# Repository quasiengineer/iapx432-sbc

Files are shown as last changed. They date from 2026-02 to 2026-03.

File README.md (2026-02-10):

# System board for Intel APX 432 GDP
FPGA-based single board computer to run iAPX 432 GDP

## Board

Full schematics in [pdf format](./images/schematic.pdf)

Here is shown only FPGA part of the board:
schematic

Archive with gerber files and drill locations could be found [here](./pcb/manufacturing.zip)

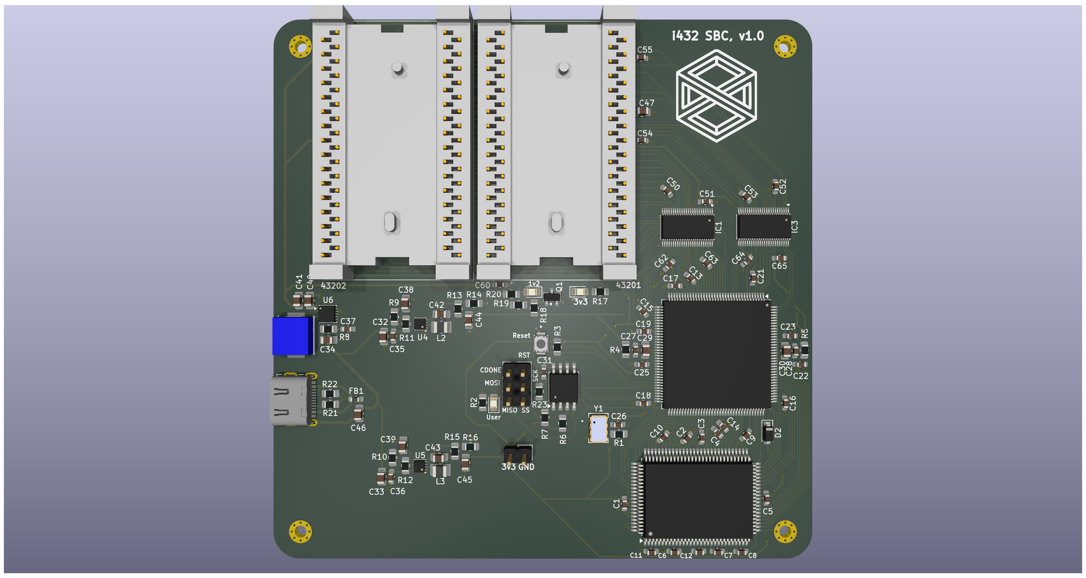
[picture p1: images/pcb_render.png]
pcb


Bill of material in [CSV format](./pcb/bom.csv)

| Reference | Qty | Value | Mouser Part Number |
|---|---|---|---|
| Y1 | 1 | 250Mhz | 972-XLH536250000000I |
| U1 | 1 | SRAM | 870-61LPS12836A5TQL  |
| U2 | 1 | ICE40 | 842-ICE40HX4K-TQ144  |
| FB1 | 1 | Ferrite_Bead | 81-BLM18BD152SH1D |
| D1 | 1 | Red | 710-150080RS75000 |
| D3,D4 | 2 | Green | 710-150080GS75000 |
| J1 | 1 | Type-C | 656-DX07S016JA1R1500 |
| L1 | 1 | 1u5, 5A | 652-SRP6530A-1R5M |
| L2,L3 | 2 | 0u68, 5.5A | 652-SRP2512-R68M |
| J3 | 1 | Power | 649-67997-200HLF |
| J2 | 1 | FPGA programming / UART | 649-1012938190604BLF |
| SW1 | 1 | FPGA Reset | 640-SWT0010015016SSA |
| Q1 | 1 | MMBT3904 | 637-MMBT3904 |
| D2 | 1 | 1N5819 | 621-1N5819HW-F |
| R11,R12,R13,R14,R19 | 5 | 100k | 603-RT0805DRE07100KL |
| R23 | 1 | 470R | 603-RT0805BRD07470RL |
| R21,R22 | 2 | 5k1 | 603-RC0805FR-075K1L  |
| R2,R18 | 2 | 4k7 | 603-RC0805FR-074K7L  |
| R16 | 1 | 34k8 | 603-RC0805FR-0734K8L |
| R17,R20 | 2 | 2k2 | 603-RC0805FR-072K2L  |
| R15 | 1 | 158k | 603-RC0805FR-07158KL |
| R1 | 1 | 22R | 603-RC0805FR-1322RL  |
| C43 | 1 | 33p | 603-CC805KRNPO9BN330 |
| C42 | 1 | 22p | 603-CC805JRNPO9BN220 |
| R9,R10 | 2 | 10 | 603-AF0805FR-0710RL  |
| R4,R5,R8 | 3 | 100R | 603-AC0805FR-13100RL |
| R3,R6,R7 | 3 | 10k | 603-AA0805FR-0710KL  |
| U6 | 1 | TPS63002 | 595-TPS63002DRCR |
| IC3 | 1 | Control signals | 595-LVC16T245DGVRG4  |
| IC1 | 1 | Address/data bus | 595-LVC16T245DGVRG4  |
| U4,U5 | 2 | LX7167ACLD-TR | 494-LX7167ACLD-TR |
| U3 | 1 | Bitstream flash | 454-W25Q16JVSSIQ |
| C38,C39,C46,C47 | 4 | 1u | 187-CL21B105KPFNNNE  |
| C29,C30,C32,C33,C44,C45 | 6 | 22u | 187-CL21A226MAYNNNE  |
| C34,C40,C41 | 3 | 10u | 187-CL21A106KQFNNNG  |
| C1..C19,C21,C22,C23,C25..C28,C31,C35,C36,C37,C50..C65 | 46  | 100n | 187-CL10B104KB8NNNC  |
| U8 | 1 | 43202 | |
| U7 | 1 | 43201 | |

## FPGA bitstream

Here is compiled [bitsream](./gateware/build/iapx432-sbc.bin).
You can flash it to memory chip via SPI programmer (there is 6-pin header for that).

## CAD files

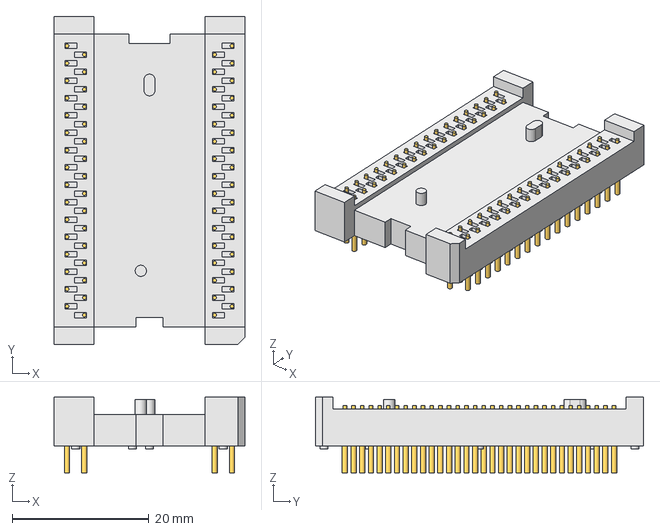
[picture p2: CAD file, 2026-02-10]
pcb/components/3d/3M_QUIP64.step
27.9 x 48.0 x 11.1 mm

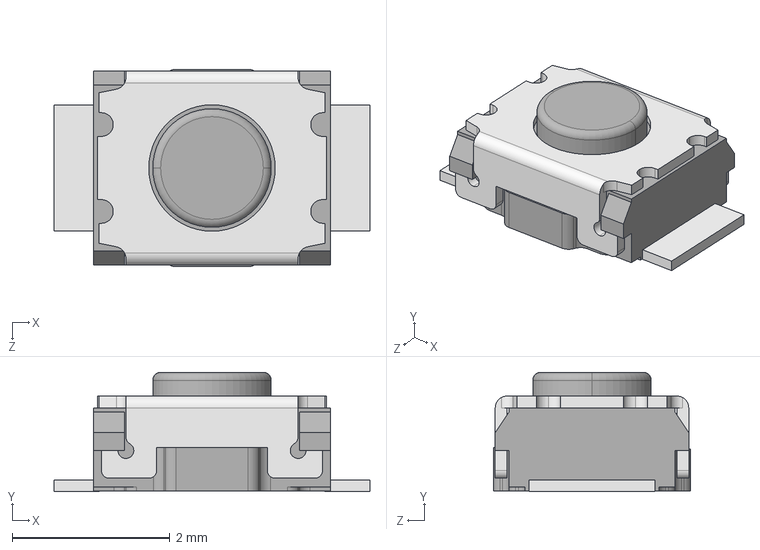
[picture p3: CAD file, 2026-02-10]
pcb/components/3d/SWT0010-015016SSA_revA.STEP
4.00 x 1.51 x 2.50 mm

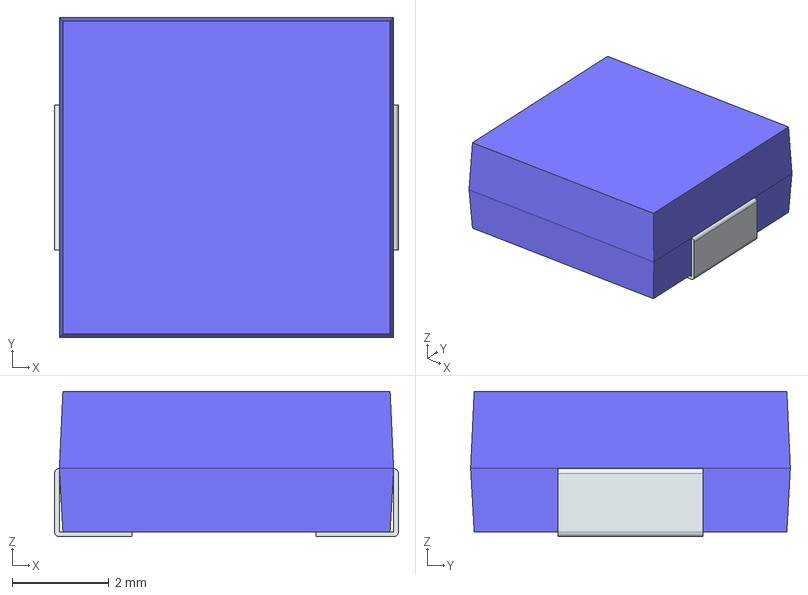
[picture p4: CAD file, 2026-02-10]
pcb/components/3d/SRP6530A-1R5M.stp
7.10 x 6.60 x 3.00 mm
FilletPin1
FilletPin2

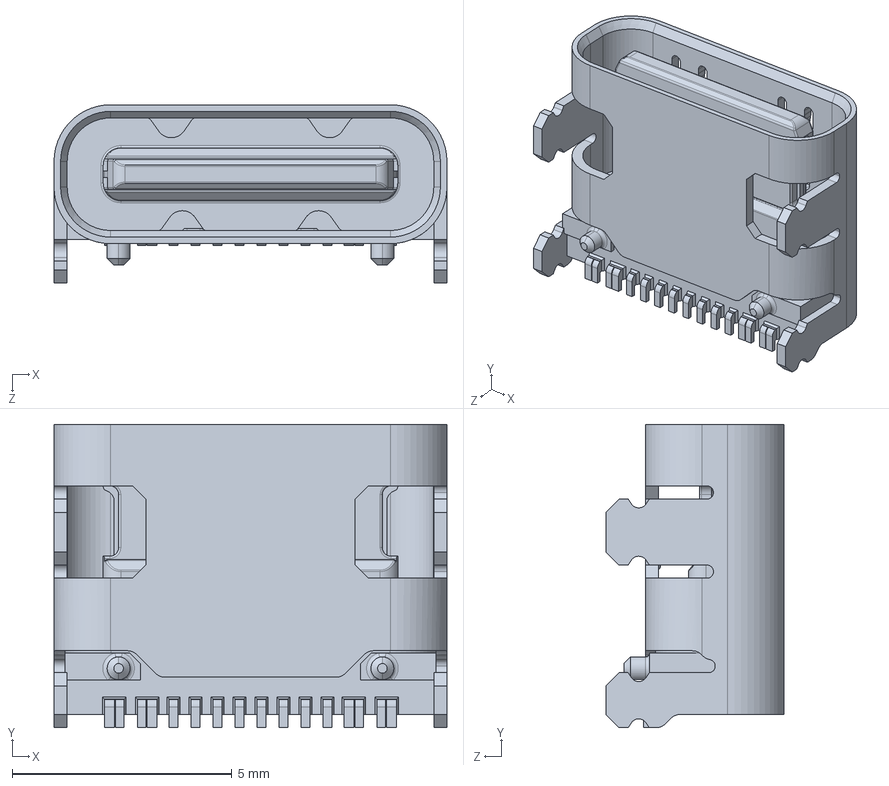
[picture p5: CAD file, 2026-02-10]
pcb/components/3d/DX07S016JA1R1500.stp
8.94 x 6.90 x 4.06 mm

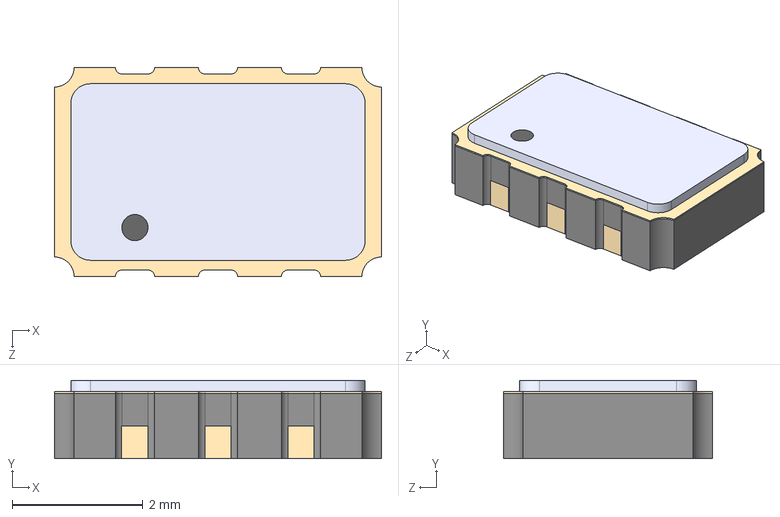
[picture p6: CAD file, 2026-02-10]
pcb/components/3d/XLH536250.000000I.STEP
5.00 x 1.20 x 3.20 mm

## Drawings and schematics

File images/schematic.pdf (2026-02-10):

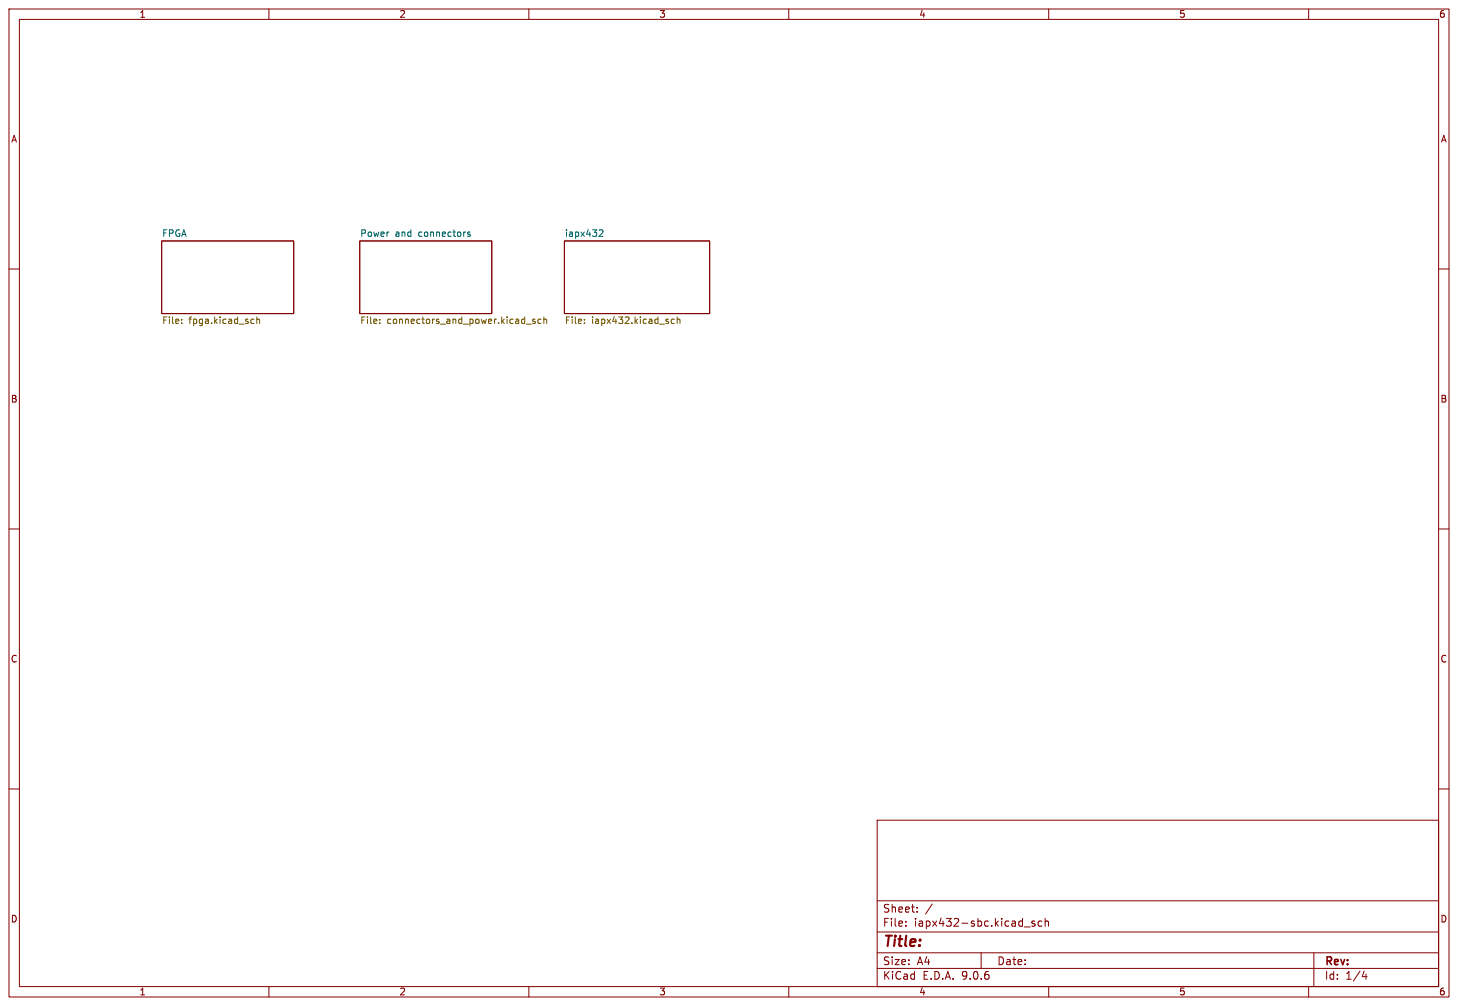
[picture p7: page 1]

iapx432 File: iapx432.kicad_sch Power and connectors File: connectors_and_power.kicad_sch

Id: 1/4 Title: File: iapx432-sbc.kicad_sch Sheet: /

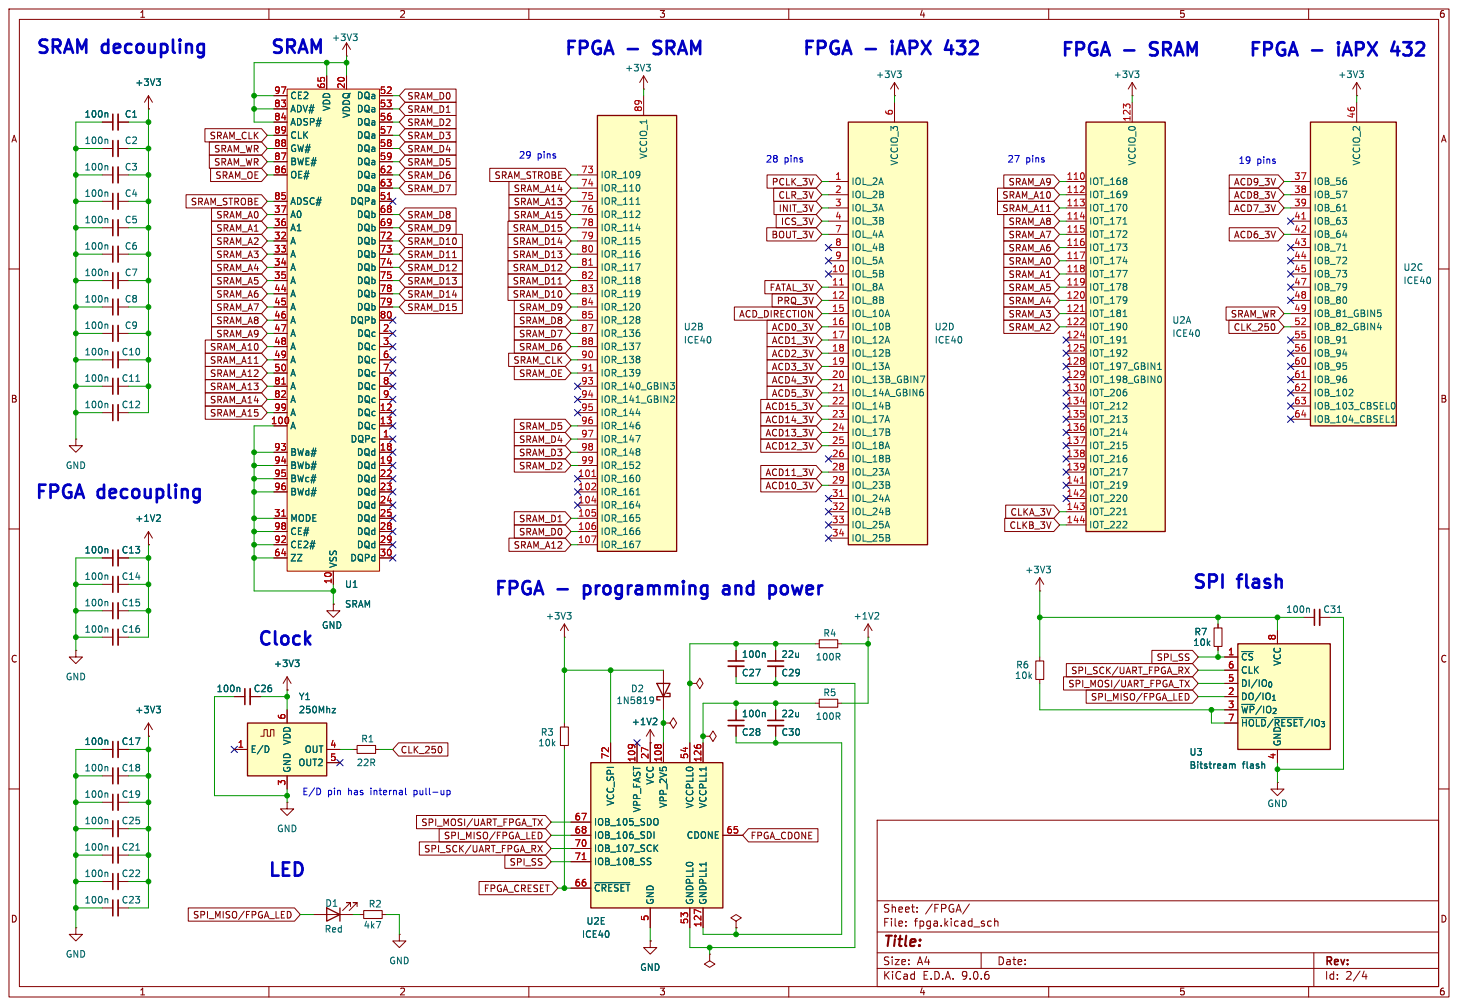
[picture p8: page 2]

+3V3 GND
CE2 97 ADV# 83 ADSP# 84 CLK 89 GW# 88 BWE# 87 OE# 86 ADSC# 85 A0 37 A1 36 A

Id: 2/4 Title: File: fpga.kicad_sch Sheet: /FPGA/

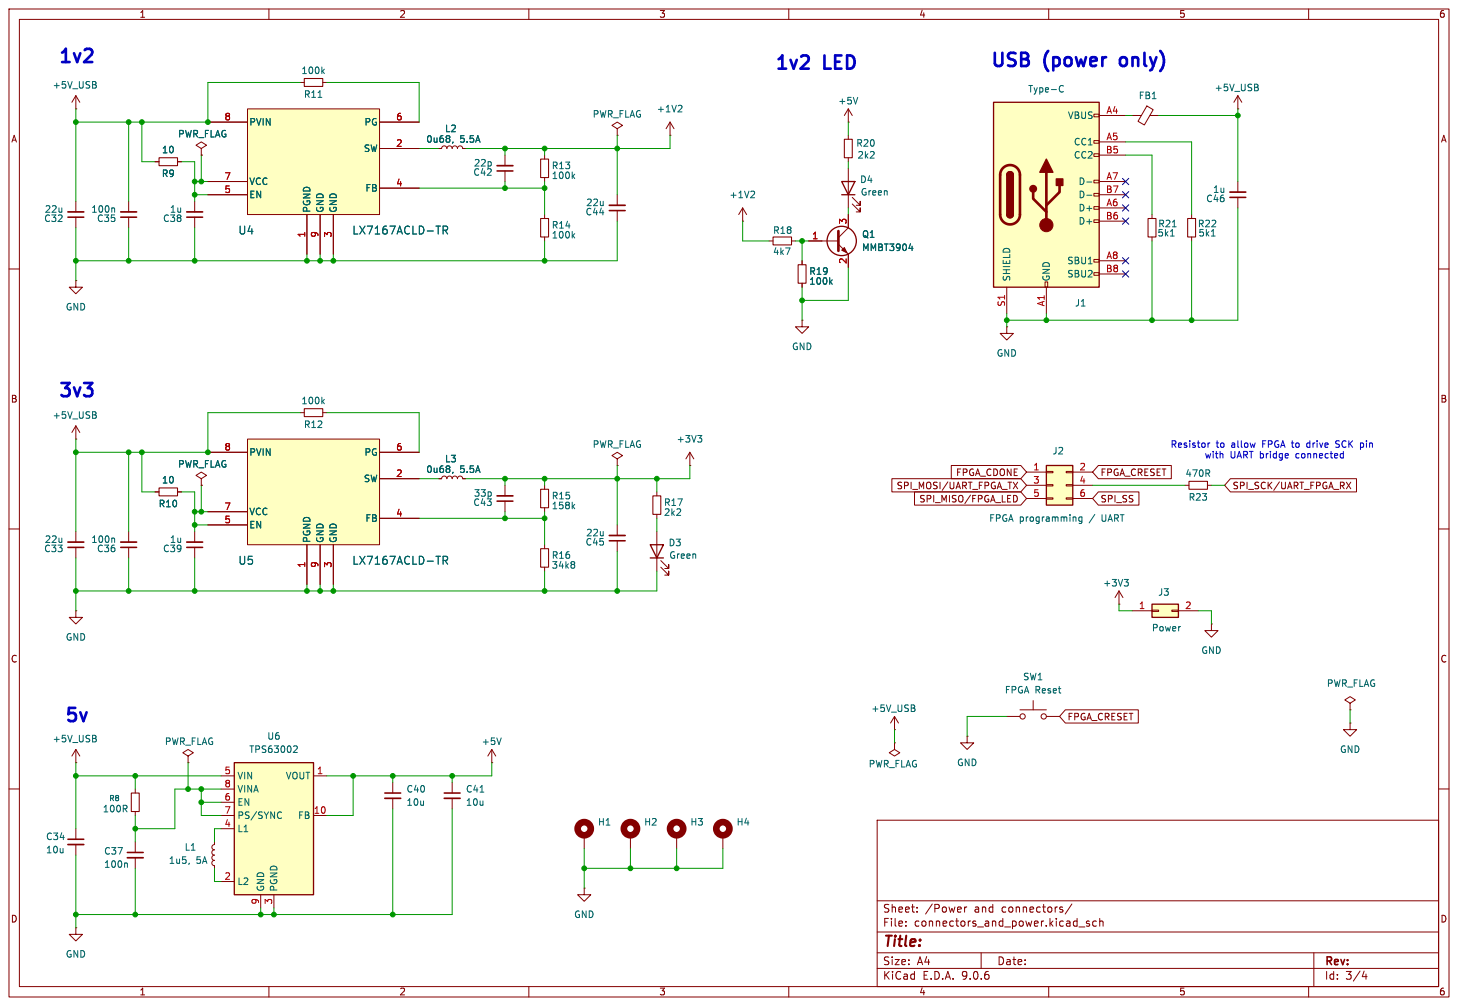
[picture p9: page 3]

3 PG 6 SW 2 FB 4 U4 LX7167ACLD-TR

3 PG 6 SW 2 FB 4 U5 LX7167ACLD-TR

VIN 5 VINA 8 EN 6 PS/SYNC 7

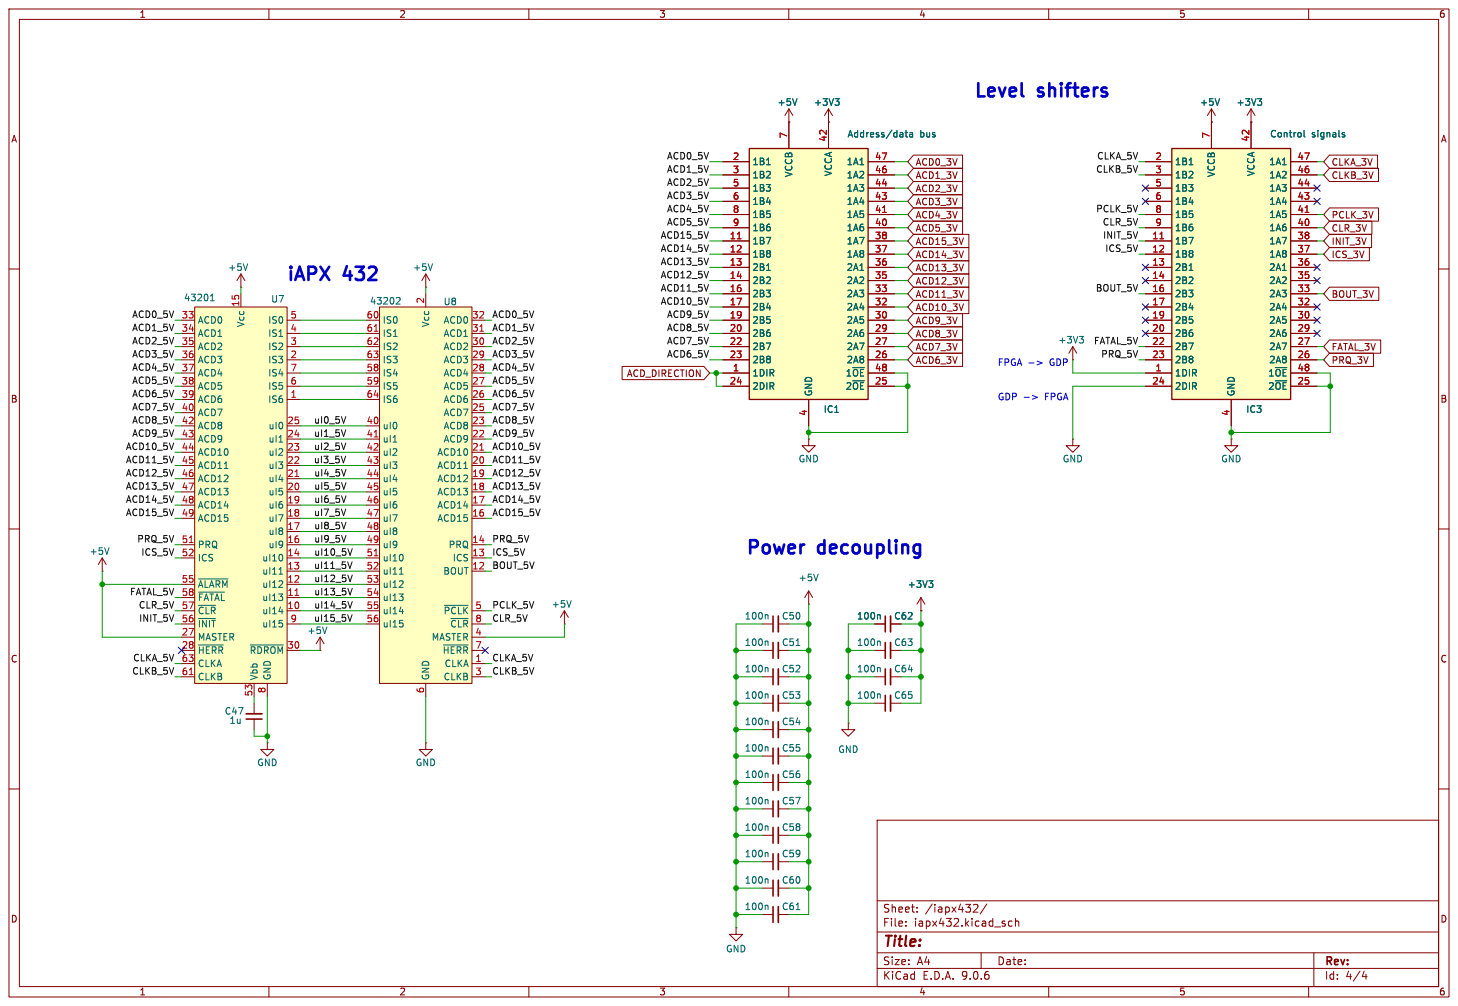
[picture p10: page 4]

ICS 13 BOUT 12 ~{PCLK}5 ~{CLR}8 MASTER 4 ~{HERR}7 CLKA 1 CLKB 3 Vcc 2 GND
ACD0 32 ACD1 31 ACD2 30 ACD3 29 ACD4 28 ACD5 27 ACD6 26 ACD7 25 ACD8 23 ACD9 22 ACD10 21 ACD11 20 ACD12 19 ACD13 18 ACD14 17 ACD15 16 PRQ 14

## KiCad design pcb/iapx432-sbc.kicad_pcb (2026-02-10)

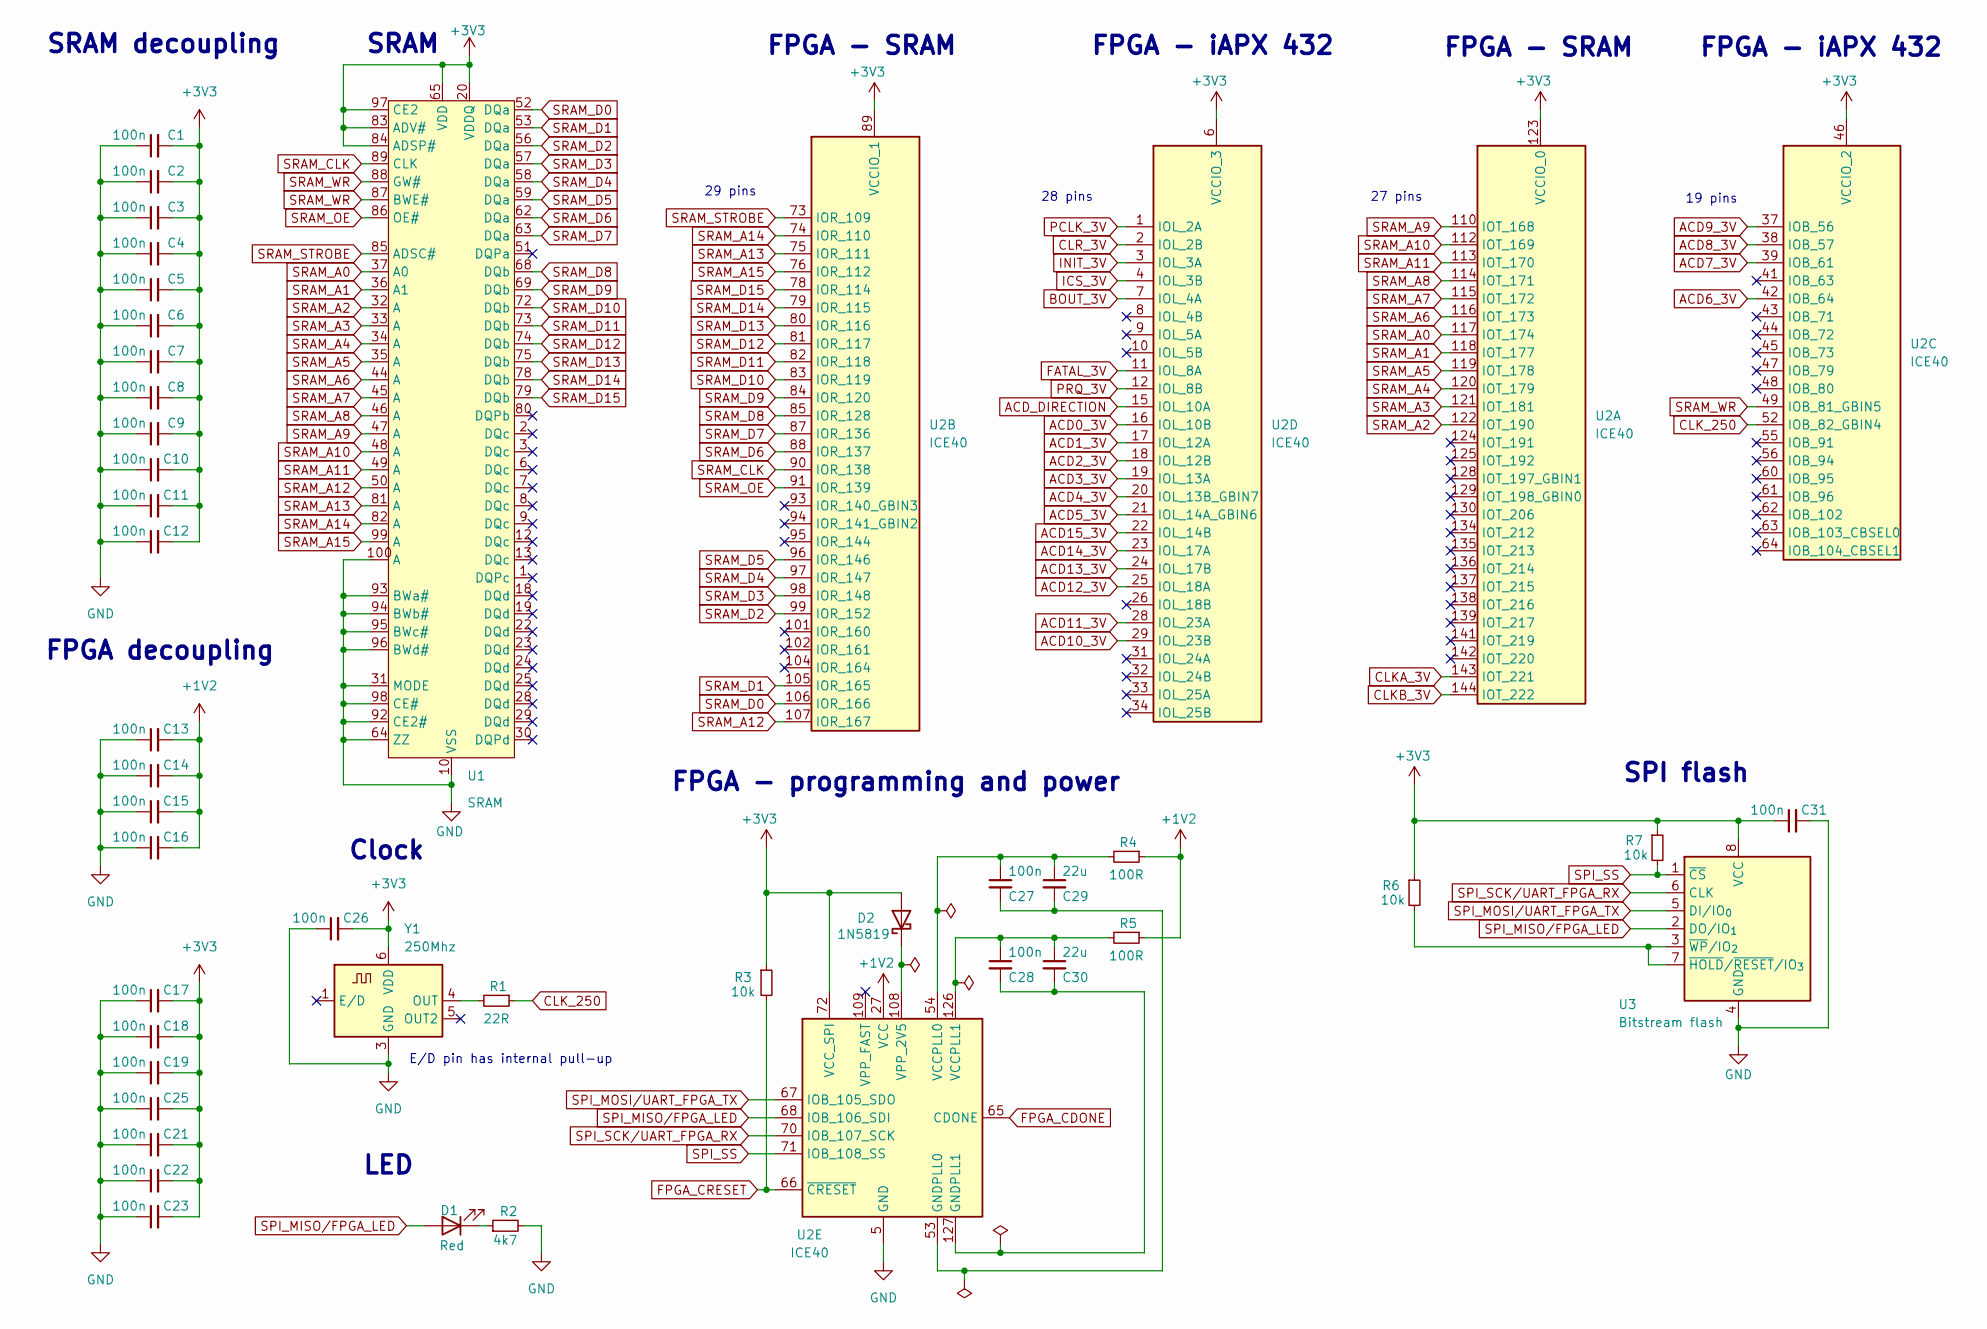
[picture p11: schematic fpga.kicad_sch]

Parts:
C1, C2, C3, C4, C5, C6, C7, C8, C9, C10, C11, C12, C13, C14, C15, C16, C17, C18, C19, C21, C22, C23, C25, C26, C27, C28, C31: 100n; C_0603_1608Metric_Pad1.08x0.95mm_HandSolder; Mouser Part Number 187-CL10B104KB8NNNC
C29, C30: 22u; C_0805_2012Metric_Pad1.18x1.45mm_HandSolder; Mouser Part Number 187-CL21A226MAYNNNE
D1: Red; LED_0805_2012Metric_Pad1.15x1.40mm_HandSolder; Mouser Part Number 710-150080RS75000
D2: 1N5819; D_SOD-123; Mouser Part Number 621-1N5819HW-F
R1: 22R; R_0805_2012Metric_Pad1.20x1.40mm_HandSolder; Mouser Part Number 603-RC0805FR-1322RL
R2: 4k7; R_0805_2012Metric_Pad1.20x1.40mm_HandSolder; Mouser Part Number 603-RC0805FR-074K7L
R3, R6, R7: 10k; R_0805_2012Metric_Pad1.20x1.40mm_HandSolder; Mouser Part Number 603-AA0805FR-0710KL
R4, R5: 100R; R_0805_2012Metric_Pad1.20x1.40mm_HandSolder; Mouser Part Number 603-AC0805FR-13100RL
U1: SRAM; PQFP-100_14x20mm_P0.65mm; Mouser Part Number 870-61LPS12836A5TQL
U2: ICE40; TQFP-144_20x20mm_P0.5mm; Mouser Part Number 842-ICE40HX4K-TQ144
U3: Bitstream flash; SOIC-8_5.3x5.3mm_P1.27mm; Mouser Part Number 454-W25Q16JVSSIQ
Y1: 250Mhz; XLH536250.000000I; Mouser Part Number 972-XLH536250000000I

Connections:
+1V2: C13.2, C14.2, C15.2, C16.2, R4.1, R5.1, U2.27 (VCC), U2.40 (VCC), U2.92 (VCC), U2.111 (VCC); also elsewhere on the board
+3V3: C1.2, C2.2, C3.2, C4.2, C5.2, C6.2, C7.2, C8.2, C9.2, C10.2, C11.2, C12.2, C17.2, C18.2, C19.2, C21.2, C22.2, C23.2, C25.2, C26.2, C31.1, D2.2 (A), R3.1, R6.1, R7.1, U1.4 (VDDQ), U1.11 (VDDQ), U1.15 (VDD), U1.20 (VDDQ), U1.27 (VDDQ), U1.41 (VDD), U1.54 (VDDQ), U1.61 (VDDQ), U1.65 (VDD), U1.70 (VDDQ), U1.77 (VDDQ), U1.83 (ADV#), U1.84 (ADSP#), U1.91 (VDD), U1.97 (CE2), U2.6 (VCCIO_3), U2.30 (VCCIO_3), U2.46 (VCCIO_2), U2.57 (VCCIO_2), U2.72 (VCC_SPI), U2.89 (VCCIO_1), U2.100 (VCCIO_1), U2.123 (VCCIO_0), U2.131 (VCCIO_0), U3.8 (VCC), Y1.6 (VDD); also elsewhere on the board
ACD0_3V: U2.16 (IOL_10B); also elsewhere on the board
ACD1_3V: U2.17 (IOL_12A); also elsewhere on the board
ACD2_3V: U2.18 (IOL_12B); also elsewhere on the board
ACD3_3V: U2.19 (IOL_13A); also elsewhere on the board
ACD4_3V: U2.20 (IOL_13B_GBIN7); also elsewhere on the board
ACD5_3V: U2.21 (IOL_14A_GBIN6); also elsewhere on the board
ACD6_3V: U2.42 (IOB_64); also elsewhere on the board
ACD7_3V: U2.39 (IOB_61); also elsewhere on the board
ACD8_3V: U2.38 (IOB_57); also elsewhere on the board
ACD9_3V: U2.37 (IOB_56); also elsewhere on the board
ACD10_3V: U2.29 (IOL_23B); also elsewhere on the board
ACD11_3V: U2.28 (IOL_23A); also elsewhere on the board
ACD12_3V: U2.25 (IOL_18A); also elsewhere on the board
ACD13_3V: U2.24 (IOL_17B); also elsewhere on the board
ACD14_3V: U2.23 (IOL_17A); also elsewhere on the board
ACD15_3V: U2.22 (IOL_14B); also elsewhere on the board
ACD_DIRECTION: U2.15 (IOL_10A); also elsewhere on the board
BOUT_3V: U2.7 (IOL_4A); also elsewhere on the board
CLKA_3V: U2.143 (IOT_221); also elsewhere on the board
CLKB_3V: U2.144 (IOT_222); also elsewhere on the board
CLK_250: R1.1, U2.52 (IOB_82_GBIN4)
CLR_3V: U2.2 (IOL_2B); also elsewhere on the board
FATAL_3V: U2.11 (IOL_8A); also elsewhere on the board
FPGA_CDONE: U2.65 (CDONE); also elsewhere on the board
FPGA_CRESET: R3.2, U2.66 (~CRESET); also elsewhere on the board
GND: C1.1, C2.1, C3.1, C4.1, C5.1, C6.1, C7.1, C8.1, C9.1, C10.1, C11.1, C12.1, C13.1, C14.1, C15.1, C16.1, C17.1, C18.1, C19.1, C21.1, C22.1, C23.1, C25.1, C26.1, C31.2, R2.2, U1.5 (VSS), U1.10 (VSS), U1.17 (VSS), U1.21 (VSS), U1.26 (VSS), U1.31 (MODE), U1.40 (VSS), U1.55 (VSS), U1.60 (VSS), U1.64 (ZZ), U1.67 (VSS), U1.71 (VSS), U1.76 (VSS), U1.90 (VSS), U1.92 (CE2#), U1.93 (BWa#), U1.94 (BWb#), U1.95 (BWc#), U1.96 (BWd#), U1.98 (CE#), U1.100 (A), U2.5 (GND), U2.13 (GND), U2.14 (GND), U2.59 (GND), U2.69 (GND), U2.86 (GND), U2.103 (GND), U2.132 (GND), U2.140 (GND), U3.4 (GND), Y1.3 (GND); also elsewhere on the board
ICS_3V: U2.4 (IOL_3B); also elsewhere on the board
INIT_3V: U2.3 (IOL_3A); also elsewhere on the board
unnamed: D1.1 (K), R2.1
unnamed: D2.1 (K), U2.108 (VPP_2V5)
unnamed: C27.2, C29.2, U2.53 (GNDPLL0)
unnamed: C28.2, C30.2, U2.127 (GNDPLL1)
unnamed: C27.1, C29.1, R4.2, U2.54 (VCCPLL0)
unnamed: C28.1, C30.1, R5.2, U2.126 (VCCPLL1)
unnamed: R6.2, U3.3 (~WP/IO_{2}), U3.7 (~HOLD/~RESET/IO_{3})
unnamed: R1.2, Y1.4 (OUT)
PCLK_3V: U2.1 (IOL_2A); also elsewhere on the board
PRQ_3V: U2.12 (IOL_8B); also elsewhere on the board
SPI_MISO/FPGA_LED: D1.2 (A), U2.68 (IOB_106_SDI), U3.2 (DO/IO_{1}); also elsewhere on the board
SPI_MOSI/UART_FPGA_TX: U2.67 (IOB_105_SDO), U3.5 (DI/IO_{0}); also elsewhere on the board
SPI_SCK/UART_FPGA_RX: U2.70 (IOB_107_SCK), U3.6 (CLK); also elsewhere on the board
SPI_SS: R7.2, U2.71 (IOB_108_SS), U3.1 (~CS); also elsewhere on the board
SRAM_A0: U1.37 (A0), U2.117 (IOT_174)
SRAM_A1: U1.36 (A1), U2.118 (IOT_177)
SRAM_A2: U1.32 (A), U2.122 (IOT_190)
SRAM_A3: U1.33 (A), U2.121 (IOT_181)
SRAM_A4: U1.34 (A), U2.120 (IOT_179)
SRAM_A5: U1.35 (A), U2.119 (IOT_178)
SRAM_A6: U1.44 (A), U2.116 (IOT_173)
SRAM_A7: U1.45 (A), U2.115 (IOT_172)
SRAM_A8: U1.46 (A), U2.114 (IOT_171)
SRAM_A9: U1.47 (A), U2.110 (IOT_168)
SRAM_A10: U1.48 (A), U2.112 (IOT_169)
SRAM_A11: U1.49 (A), U2.113 (IOT_170)
SRAM_A12: U1.50 (A), U2.107 (IOR_167)
SRAM_A13: U1.81 (A), U2.75 (IOR_111)
SRAM_A14: U1.82 (A), U2.74 (IOR_110)
SRAM_A15: U1.99 (A), U2.76 (IOR_112)
SRAM_CLK: U1.89 (CLK), U2.90 (IOR_138)
SRAM_D0: U1.52 (DQa), U2.106 (IOR_166)
SRAM_D1: U1.53 (DQa), U2.105 (IOR_165)
SRAM_D2: U1.56 (DQa), U2.99 (IOR_152)
SRAM_D3: U1.57 (DQa), U2.98 (IOR_148)
SRAM_D4: U1.58 (DQa), U2.97 (IOR_147)
SRAM_D5: U1.59 (DQa), U2.96 (IOR_146)
SRAM_D6: U1.62 (DQa), U2.88 (IOR_137)
SRAM_D7: U1.63 (DQa), U2.87 (IOR_136)
SRAM_D8: U1.68 (DQb), U2.85 (IOR_128)
SRAM_D9: U1.69 (DQb), U2.84 (IOR_120)
SRAM_D10: U1.72 (DQb), U2.83 (IOR_119)
SRAM_D11: U1.73 (DQb), U2.82 (IOR_118)
SRAM_D12: U1.74 (DQb), U2.81 (IOR_117)
SRAM_D13: U1.75 (DQb), U2.80 (IOR_116)
SRAM_D14: U1.78 (DQb), U2.79 (IOR_115)
SRAM_D15: U1.79 (DQb), U2.78 (IOR_114)
SRAM_OE: U1.86 (OE#), U2.91 (IOR_139)
SRAM_STROBE: U1.85 (ADSC#), U2.73 (IOR_109)
SRAM_WR: U1.87 (BWE#), U1.88 (GW#), U2.49 (IOB_81_GBIN5)

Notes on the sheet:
Clock
SRAM
FPGA decoupling
FPGA - SRAM
FPGA - iAPX 432
28 pins
19 pins
27 pins
FPGA - programming and power
E/D pin has internal pull-up
SRAM decoupling
SPI flash
LED
29 pins

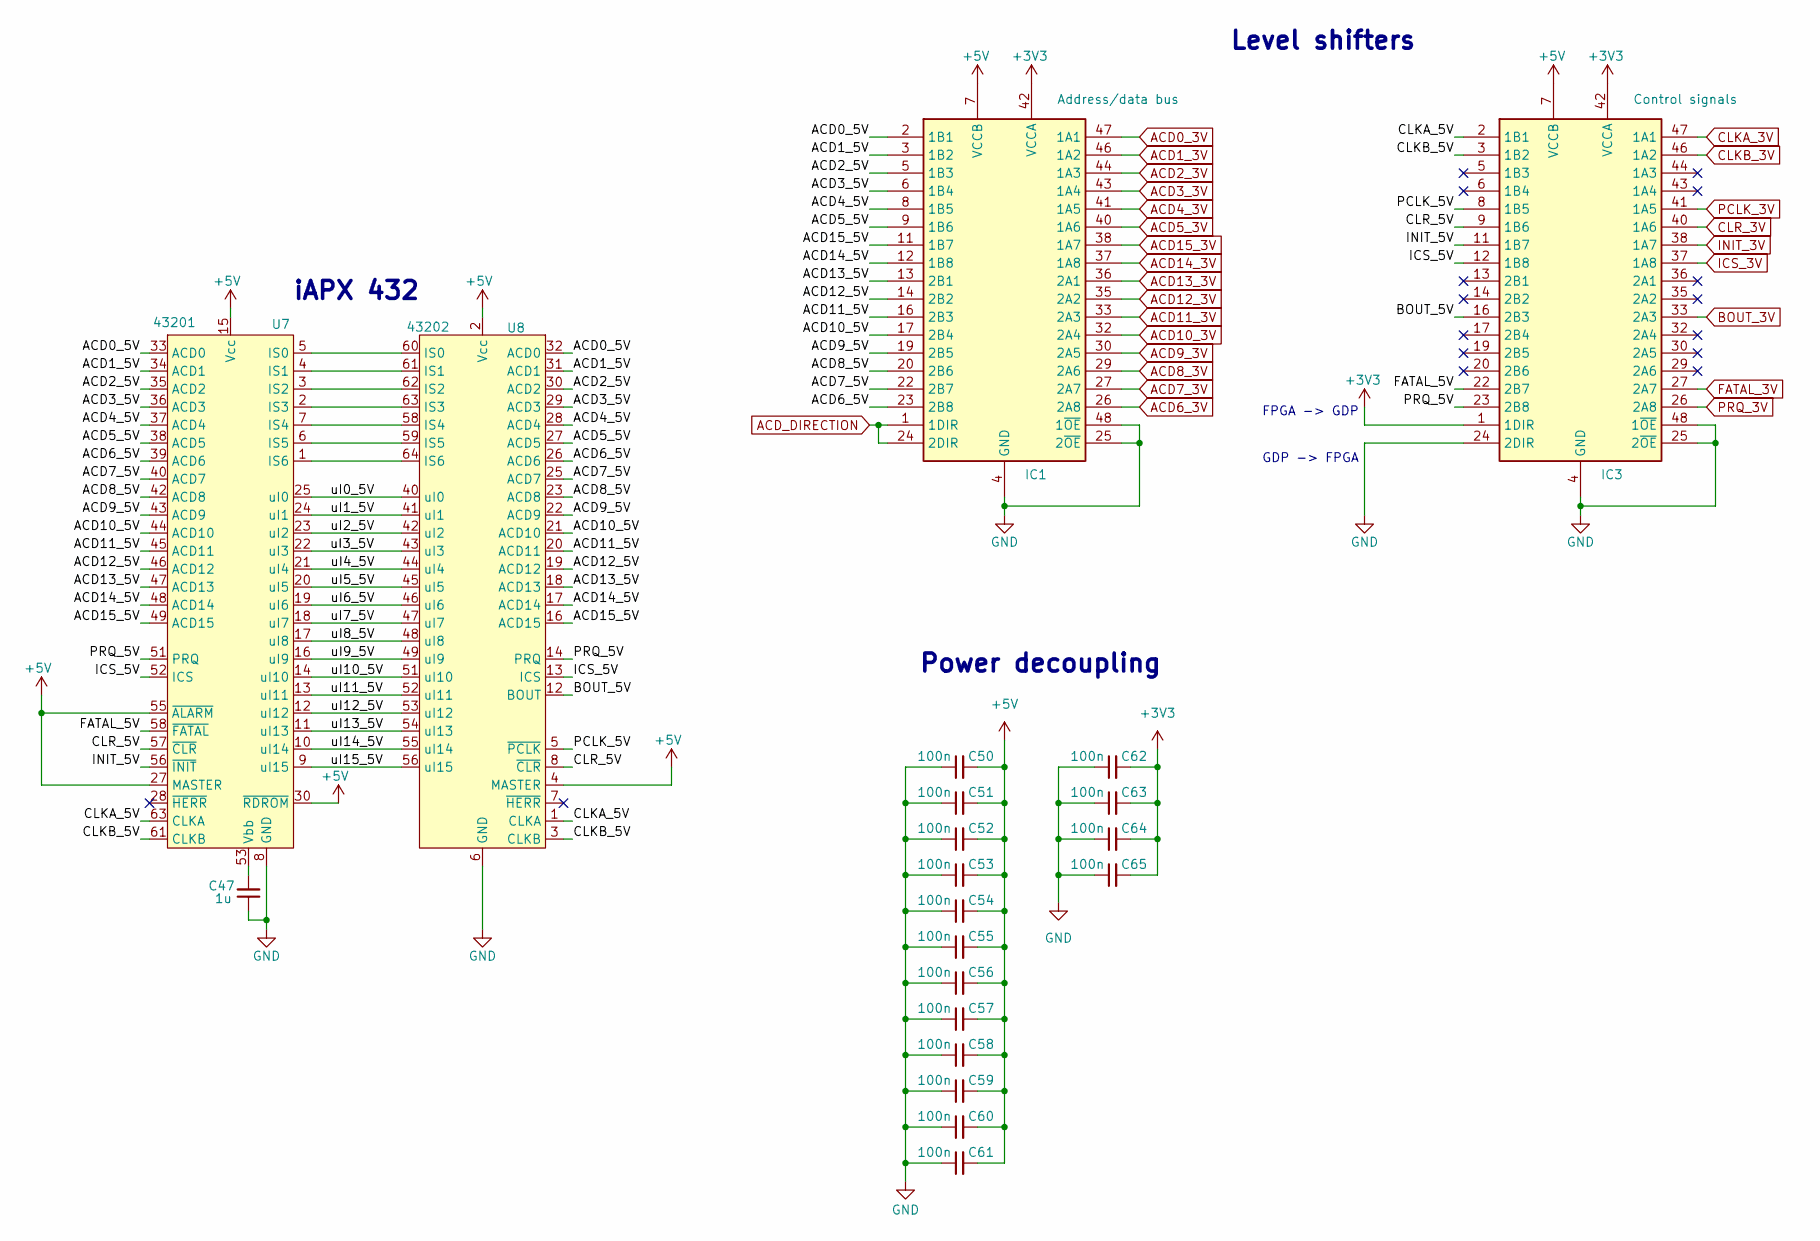
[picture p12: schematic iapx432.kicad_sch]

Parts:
C47: 1u; C_0805_2012Metric_Pad1.18x1.45mm_HandSolder; Mouser Part Number 187-CL21B105KPFNNNE
C50, C51, C52, C53, C54, C55, C56, C57, C58, C59, C60, C61, C62, C63, C64, C65: 100n; C_0603_1608Metric_Pad1.08x0.95mm_HandSolder; Mouser Part Number 187-CL10B104KB8NNNC
IC1: Address/data bus; TSSOP-48_4.4x9.7mm_P0.4mm; Mouser Part Number 595-LVC16T245DGVRG4
IC3: Control signals; TSSOP-48_4.4x9.7mm_P0.4mm; Mouser Part Number 595-LVC16T245DGVRG4
U7: 43201; 3M_QUIP64
U8: 43202; 3M_QUIP64

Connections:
+3V3: C62.2, C63.2, C64.2, C65.2, IC1.31 (VCCA), IC1.42 (VCCA), IC3.1 (1DIR), IC3.31 (VCCA), IC3.42 (VCCA); also elsewhere on the board
+5V: C50.2, C51.2, C52.2, C53.2, C54.2, C55.2, C56.2, C57.2, C58.2, C59.2, C60.2, C61.2, IC1.7 (VCCB), IC1.18 (VCCB), IC3.7 (VCCB), IC3.18 (VCCB), U7.15 (Vcc), U7.27 (MASTER), U7.30 (~RDROM), U7.32 (Vcc), U7.50 (Vcc), U7.55 (~ALARM), U7.62 (Vcc), U8.2 (Vcc), U8.4 (MASTER), U8.15 (Vcc), U8.38 (Vcc), U8.50 (Vcc); also elsewhere on the board
/iapx432/ACD0_5V: IC1.2 (1B1), U7.33 (ACD0), U8.32 (ACD0)
/iapx432/ACD1_5V: IC1.3 (1B2), U7.34 (ACD1), U8.31 (ACD1)
/iapx432/ACD2_5V: IC1.5 (1B3), U7.35 (ACD2), U8.30 (ACD2)
/iapx432/ACD3_5V: IC1.6 (1B4), U7.36 (ACD3), U8.29 (ACD3)
/iapx432/ACD4_5V: IC1.8 (1B5), U7.37 (ACD4), U8.28 (ACD4)
/iapx432/ACD5_5V: IC1.9 (1B6), U7.38 (ACD5), U8.27 (ACD5)
/iapx432/ACD6_5V: IC1.23 (2B8), U7.39 (ACD6), U8.26 (ACD6)
/iapx432/ACD7_5V: IC1.22 (2B7), U7.40 (ACD7), U8.25 (ACD7)
/iapx432/ACD8_5V: IC1.20 (2B6), U7.42 (ACD8), U8.23 (ACD8)
/iapx432/ACD9_5V: IC1.19 (2B5), U7.43 (ACD9), U8.22 (ACD9)
/iapx432/ACD10_5V: IC1.17 (2B4), U7.44 (ACD10), U8.21 (ACD10)
/iapx432/ACD11_5V: IC1.16 (2B3), U7.45 (ACD11), U8.20 (ACD11)
/iapx432/ACD12_5V: IC1.14 (2B2), U7.46 (ACD12), U8.19 (ACD12)
/iapx432/ACD13_5V: IC1.13 (2B1), U7.47 (ACD13), U8.18 (ACD13)
/iapx432/ACD14_5V: IC1.12 (1B8), U7.48 (ACD14), U8.17 (ACD14)
/iapx432/ACD15_5V: IC1.11 (1B7), U7.49 (ACD15), U8.16 (ACD15)
/iapx432/BOUT_5V: IC3.16 (2B3), U8.12 (BOUT)
/iapx432/CLKA_5V: IC3.2 (1B1), U7.63 (CLKA), U8.1 (CLKA)
/iapx432/CLKB_5V: IC3.3 (1B2), U7.61 (CLKB), U8.3 (CLKB)
/iapx432/CLR_5V: IC3.9 (1B6), U7.57 (~CLR), U8.8 (~CLR)
/iapx432/FATAL_5V: IC3.22 (2B7), U7.58 (~FATAL)
/iapx432/ICS_5V: IC3.12 (1B8), U7.52 (ICS), U8.13 (ICS)
/iapx432/INIT_5V: IC3.11 (1B7), U7.56 (~INIT)
/iapx432/PCLK_5V: IC3.8 (1B5), U8.5 (~PCLK)
/iapx432/PRQ_5V: IC3.23 (2B8), U7.51 (PRQ), U8.14 (PRQ)
/iapx432/uI0_5V: U7.25 (uI0), U8.40 (uI0)
/iapx432/uI1_5V: U7.24 (uI1), U8.41 (uI1)
/iapx432/uI2_5V: U7.23 (uI2), U8.42 (uI2)
/iapx432/uI3_5V: U7.22 (uI3), U8.43 (uI3)
/iapx432/uI4_5V: U7.21 (uI4), U8.44 (uI4)
/iapx432/uI5_5V: U7.20 (uI5), U8.45 (uI5)
/iapx432/uI6_5V: U7.19 (uI6), U8.46 (uI6)
/iapx432/uI7_5V: U7.18 (uI7), U8.47 (uI7)
/iapx432/uI8_5V: U7.17 (uI8), U8.48 (uI8)
/iapx432/uI9_5V: U7.16 (uI9), U8.49 (uI9)
/iapx432/uI10_5V: U7.14 (uI10), U8.51 (uI10)
/iapx432/uI11_5V: U7.13 (uI11), U8.52 (uI11)
/iapx432/uI12_5V: U7.12 (uI12), U8.53 (uI12)
/iapx432/uI13_5V: U7.11 (uI13), U8.54 (uI13)
/iapx432/uI14_5V: U7.10 (uI14), U8.55 (uI14)
/iapx432/uI15_5V: U7.9 (uI15), U8.56 (uI15)
ACD0_3V: IC1.47 (1A1); also elsewhere on the board
ACD1_3V: IC1.46 (1A2); also elsewhere on the board
ACD2_3V: IC1.44 (1A3); also elsewhere on the board
ACD3_3V: IC1.43 (1A4); also elsewhere on the board
ACD4_3V: IC1.41 (1A5); also elsewhere on the board
ACD5_3V: IC1.40 (1A6); also elsewhere on the board
ACD6_3V: IC1.26 (2A8); also elsewhere on the board
ACD7_3V: IC1.27 (2A7); also elsewhere on the board
ACD8_3V: IC1.29 (2A6); also elsewhere on the board
ACD9_3V: IC1.30 (2A5); also elsewhere on the board
ACD10_3V: IC1.32 (2A4); also elsewhere on the board
ACD11_3V: IC1.33 (2A3); also elsewhere on the board
ACD12_3V: IC1.35 (2A2); also elsewhere on the board
ACD13_3V: IC1.36 (2A1); also elsewhere on the board
ACD14_3V: IC1.37 (1A8); also elsewhere on the board
ACD15_3V: IC1.38 (1A7); also elsewhere on the board
ACD_DIRECTION: IC1.1 (1DIR), IC1.24 (2DIR); also elsewhere on the board
BOUT_3V: IC3.33 (2A3); also elsewhere on the board
CLKA_3V: IC3.47 (1A1); also elsewhere on the board
CLKB_3V: IC3.46 (1A2); also elsewhere on the board
CLR_3V: IC3.40 (1A6); also elsewhere on the board
FATAL_3V: IC3.27 (2A7); also elsewhere on the board
GND: C47.1, C50.1, C51.1, C52.1, C53.1, C54.1, C55.1, C56.1, C57.1, C58.1, C59.1, C60.1, C61.1, C62.1, C63.1, C64.1, C65.1, IC1.4 (GND), IC1.10 (GND), IC1.15 (GND), IC1.21 (GND), IC1.25 (2~OE), IC1.28 (GND), IC1.34 (GND), IC1.39 (GND), IC1.45 (GND), IC1.48 (1~OE), IC3.4 (GND), IC3.10 (GND), IC3.15 (GND), IC3.21 (GND), IC3.24 (2DIR), IC3.25 (2~OE), IC3.28 (GND), IC3.34 (GND), IC3.39 (GND), IC3.45 (GND), IC3.48 (1~OE), U7.8 (GND), U7.26 (GND), U7.41 (GND), U7.60 (GND), U7.64 (GND), U8.6 (GND), U8.24 (GND), U8.35 (GND), U8.39 (GND), U8.57 (GND); also elsewhere on the board
ICS_3V: IC3.37 (1A8); also elsewhere on the board
INIT_3V: IC3.38 (1A7); also elsewhere on the board
unnamed: U7.5 (IS0), U8.60 (IS0)
unnamed: U7.4 (IS1), U8.61 (IS1)
unnamed: U7.3 (IS2), U8.62 (IS2)
unnamed: U7.2 (IS3), U8.63 (IS3)
unnamed: U7.7 (IS4), U8.58 (IS4)
unnamed: U7.6 (IS5), U8.59 (IS5)
unnamed: U7.1 (IS6), U8.64 (IS6)
unnamed: C47.2, U7.53 (Vbb)
PCLK_3V: IC3.41 (1A5); also elsewhere on the board
PRQ_3V: IC3.26 (2A8); also elsewhere on the board

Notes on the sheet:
iAPX 432
Level shifters
FPGA -> GDP
GDP -> FPGA
Power decoupling

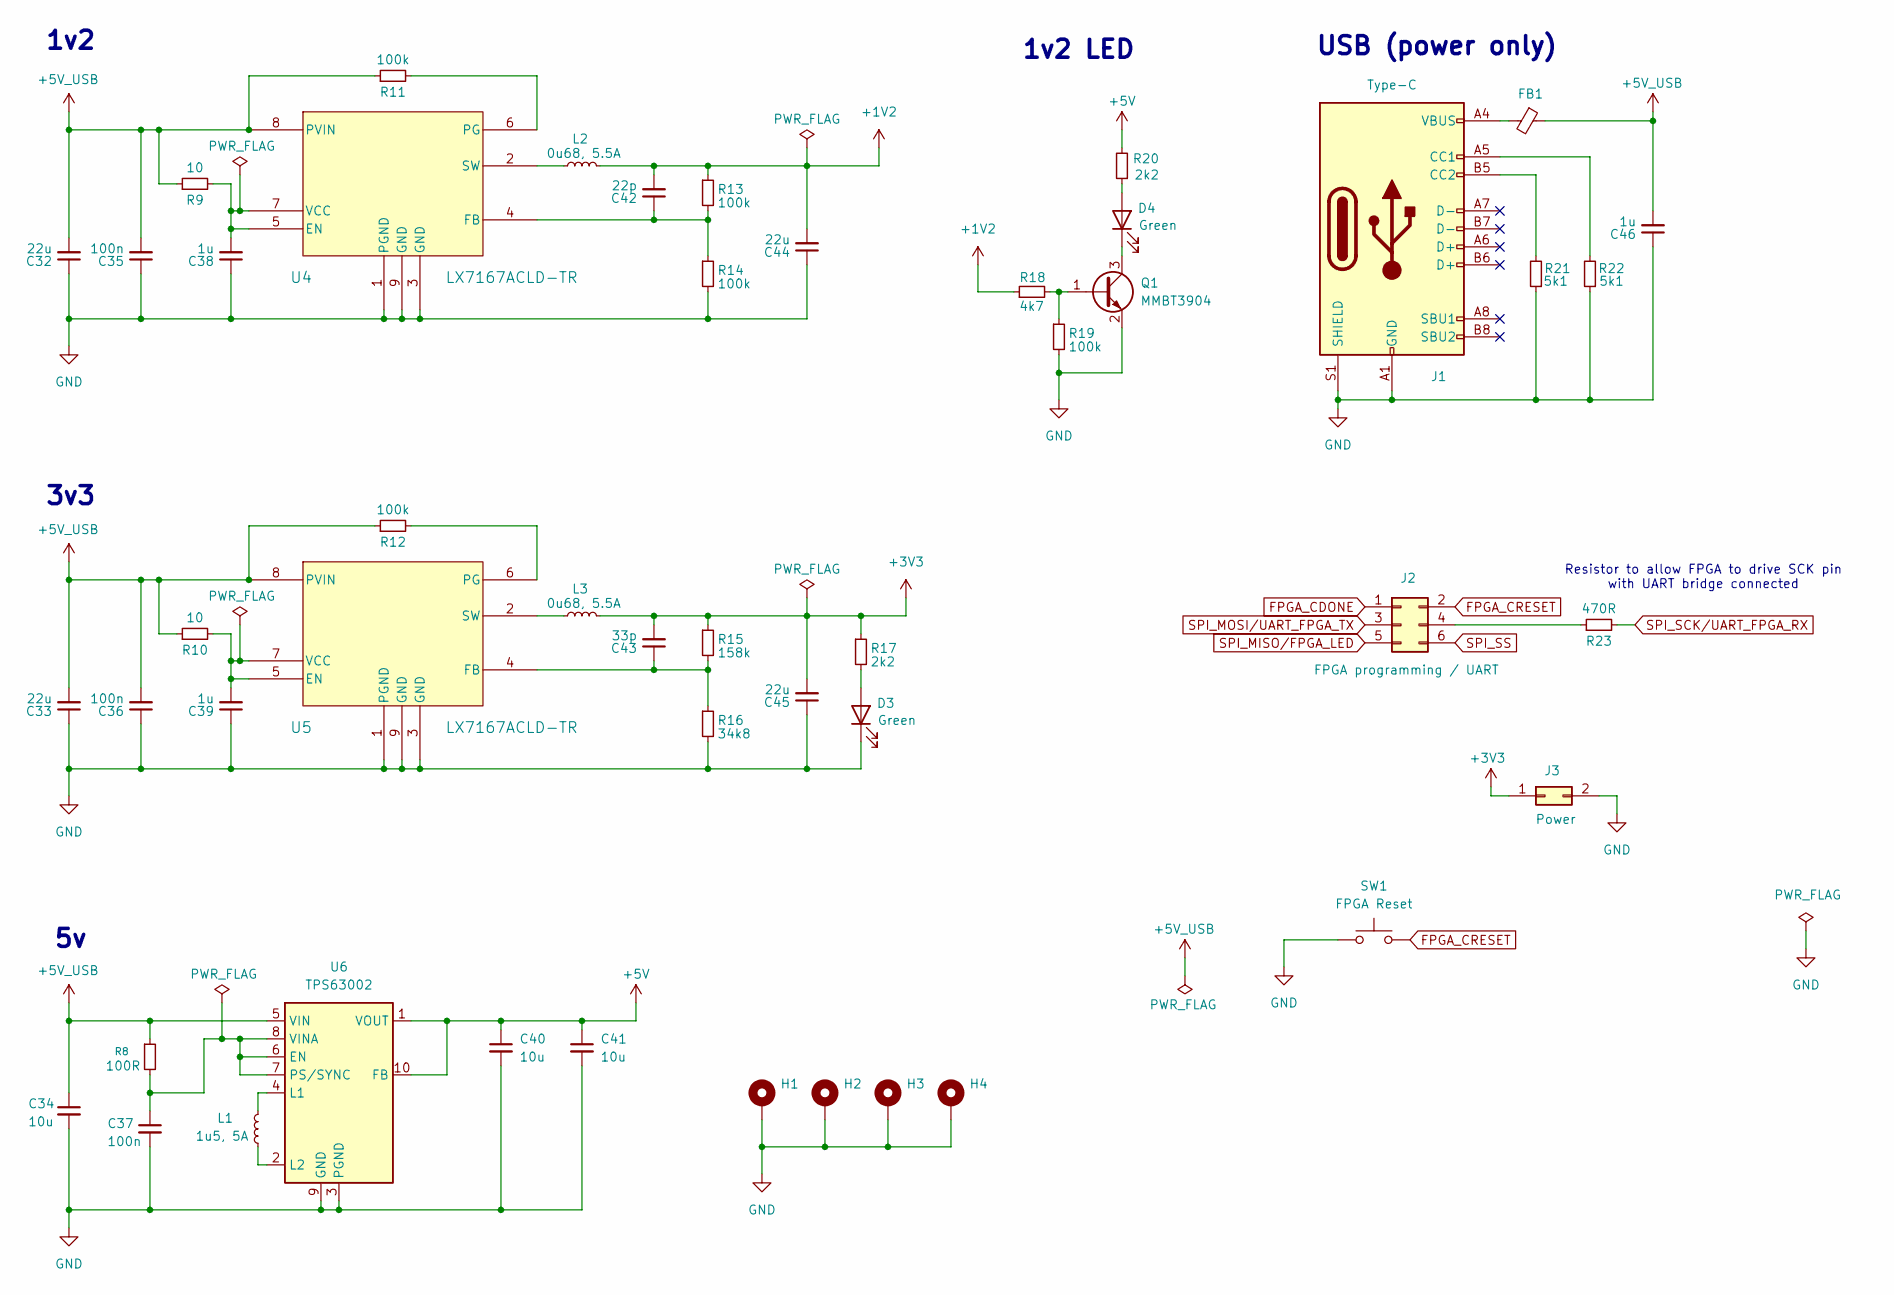
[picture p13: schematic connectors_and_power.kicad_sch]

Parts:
C32, C33, C44, C45: 22u; C_0805_2012Metric_Pad1.18x1.45mm_HandSolder; Mouser Part Number 187-CL21A226MAYNNNE
C34, C40, C41: 10u; C_0805_2012Metric_Pad1.18x1.45mm_HandSolder; Mouser Part Number 187-CL21A106KQFNNNG
C35, C36, C37: 100n; C_0603_1608Metric_Pad1.08x0.95mm_HandSolder; Mouser Part Number 187-CL10B104KB8NNNC
C38, C39, C46: 1u; C_0805_2012Metric_Pad1.18x1.45mm_HandSolder; Mouser Part Number 187-CL21B105KPFNNNE
C42: 22p; C_0805_2012Metric_Pad1.18x1.45mm_HandSolder; Mouser Part Number 603-CC805JRNPO9BN220
C43: 33p; C_0805_2012Metric_Pad1.18x1.45mm_HandSolder; Mouser Part Number 603-CC805KRNPO9BN330
D3, D4: Green; LED_0805_2012Metric_Pad1.15x1.40mm_HandSolder; Mouser Part Number 710-150080GS75000
FB1: Ferrite_Bead; L_0603_1608Metric_Pad1.05x0.95mm_HandSolder; Mouser Part Number 81-BLM18BD152SH1D
H1, H2, H3, H4: MountingHole_Pad; MountingHole_2.2mm_M2_Pad_Via
J1: Type-C; USB_C_Receptacle_JAE_DX07S016JA1R1500; Mouser Part Number 656-DX07S016JA1R1500
J2: FPGA programming / UART; PinHeader_2x03_P2.54mm_Vertical; Mouser Part Number 649-1012938190604BLF
J3: Power; PinHeader_1x02_P2.54mm_Vertical; Mouser Part Number 649-67997-200HLF
L1: 1u5, 5A; SRP6530A-1R5M; Mouser Part Number 652-SRP6530A-1R5M
L2, L3: 0u68, 5.5A; L_1008_2520Metric_Pad1.43x2.20mm_HandSolder; Mouser Part Number 652-SRP2512-R68M
Q1: MMBT3904; SOT-23; Mouser Part Number 637-MMBT3904
R8: 100R; R_0805_2012Metric_Pad1.20x1.40mm_HandSolder; Mouser Part Number 603-AC0805FR-13100RL
R9, R10: 10; R_0805_2012Metric_Pad1.20x1.40mm_HandSolder; Mouser Part Number 603-AF0805FR-0710RL
R11, R12, R13, R14, R19: 100k; R_0805_2012Metric_Pad1.20x1.40mm_HandSolder; Mouser Part Number 603-RT0805DRE07100KL
R15: 158k; R_0805_2012Metric_Pad1.20x1.40mm_HandSolder; Mouser Part Number 603-RC0805FR-07158KL
R16: 34k8; R_0805_2012Metric_Pad1.20x1.40mm_HandSolder; Mouser Part Number 603-RC0805FR-0734K8L
R17, R20: 2k2; R_0805_2012Metric_Pad1.20x1.40mm_HandSolder; Mouser Part Number 603-RC0805FR-072K2L
R18: 4k7; R_0805_2012Metric_Pad1.20x1.40mm_HandSolder; Mouser Part Number 603-RC0805FR-074K7L
R21, R22: 5k1; R_0805_2012Metric_Pad1.20x1.40mm_HandSolder; Mouser Part Number 603-RC0805FR-075K1L
R23: 470R; R_0805_2012Metric_Pad1.20x1.40mm_HandSolder; Mouser Part Number 603-RT0805BRD07470RL
SW1: FPGA Reset; SWT0010-015016SSA; Mouser Part Number 640-SWT0010015016SSA
U4, U5: LX7167ACLD-TR; DFN-8-1EP_2x2mm_P0.5mm_EP0.8x1.6mm; Mouser Part Number 494-LX7167ACLD-TR
U6: TPS63002; VSON-10-1EP_3x3mm_P0.5mm_EP1.2x2mm; Mouser Part Number 595-TPS63002DRCR

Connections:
+1V2: C42.2, C44.2, L2.2, R13.1, R18.1; also elsewhere on the board
+3V3: C43.2, C45.2, J3.1, L3.2, R15.1, R17.1; also elsewhere on the board
+5V: C40.1, C41.1, R20.2, U6.1 (VOUT), U6.10 (FB); also elsewhere on the board
+5V_USB: C32.2, C33.2, C34.1, C35.2, C36.2, C46.2, FB1.1, R8.1, R9.1, R10.1, R11.1, R12.1, U4.8 (PVIN), U5.8 (PVIN), U6.5 (VIN)
FPGA_CDONE: J2.1; also elsewhere on the board
FPGA_CRESET: J2.2, SW1.2; also elsewhere on the board
GND: C32.1, C33.1, C34.2, C35.1, C36.1, C37.2, C38.1, C39.1, C40.2, C41.2, C44.1, C45.1, C46.1, D3.1 (K), H1.1, H2.1, H3.1, H4.1, J1.A1 (GND), J1.A12 (GND), J1.B1 (GND), J1.B12 (GND), J1.S1 (SHIELD), J3.2, Q1.2 (E), R14.2, R16.2, R19.2, R21.1, R22.1, SW1.1, U4.1 (PGND), U4.3 (GND), U4.9 (GND), U5.1 (PGND), U5.3 (GND), U5.9 (GND), U6.3 (PGND), U6.9 (GND), U6.11 (PGND); also elsewhere on the board
unnamed: D3.2 (A), R17.2
unnamed: D4.2 (A), R20.1
unnamed: D4.1 (K), Q1.3 (C)
unnamed: FB1.2, J1.A4 (VBUS), J1.A9 (VBUS), J1.B4 (VBUS), J1.B9 (VBUS)
unnamed: J1.A5 (CC1), R22.2
unnamed: J1.B5 (CC2), R21.2
unnamed: J2.4, R23.1
unnamed: Q1.1 (B), R18.2, R19.1
unnamed: C38.2, R9.2, U4.5 (EN), U4.7 (VCC)
unnamed: C42.1, R13.2, R14.1, U4.4 (FB)
unnamed: R11.2, U4.6 (PG)
unnamed: L2.1, U4.2 (SW)
unnamed: C39.2, R10.2, U5.5 (EN), U5.7 (VCC)
unnamed: C43.1, R15.2, R16.1, U5.4 (FB)
unnamed: R12.2, U5.6 (PG)
unnamed: L3.1, U5.2 (SW)
unnamed: C37.1, R8.2, U6.6 (EN), U6.7 (PS/SYNC), U6.8 (VINA)
unnamed: L1.2, U6.4 (L1)
unnamed: L1.1, U6.2 (L2)
SPI_MISO/FPGA_LED: J2.5; also elsewhere on the board
SPI_MOSI/UART_FPGA_TX: J2.3; also elsewhere on the board
SPI_SCK/UART_FPGA_RX: R23.2; also elsewhere on the board
SPI_SS: J2.6; also elsewhere on the board

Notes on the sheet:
1v2 LED
Resistor to allow FPGA to drive SCK pin with UART bridge connected
3v3
1v2
USB (power only)

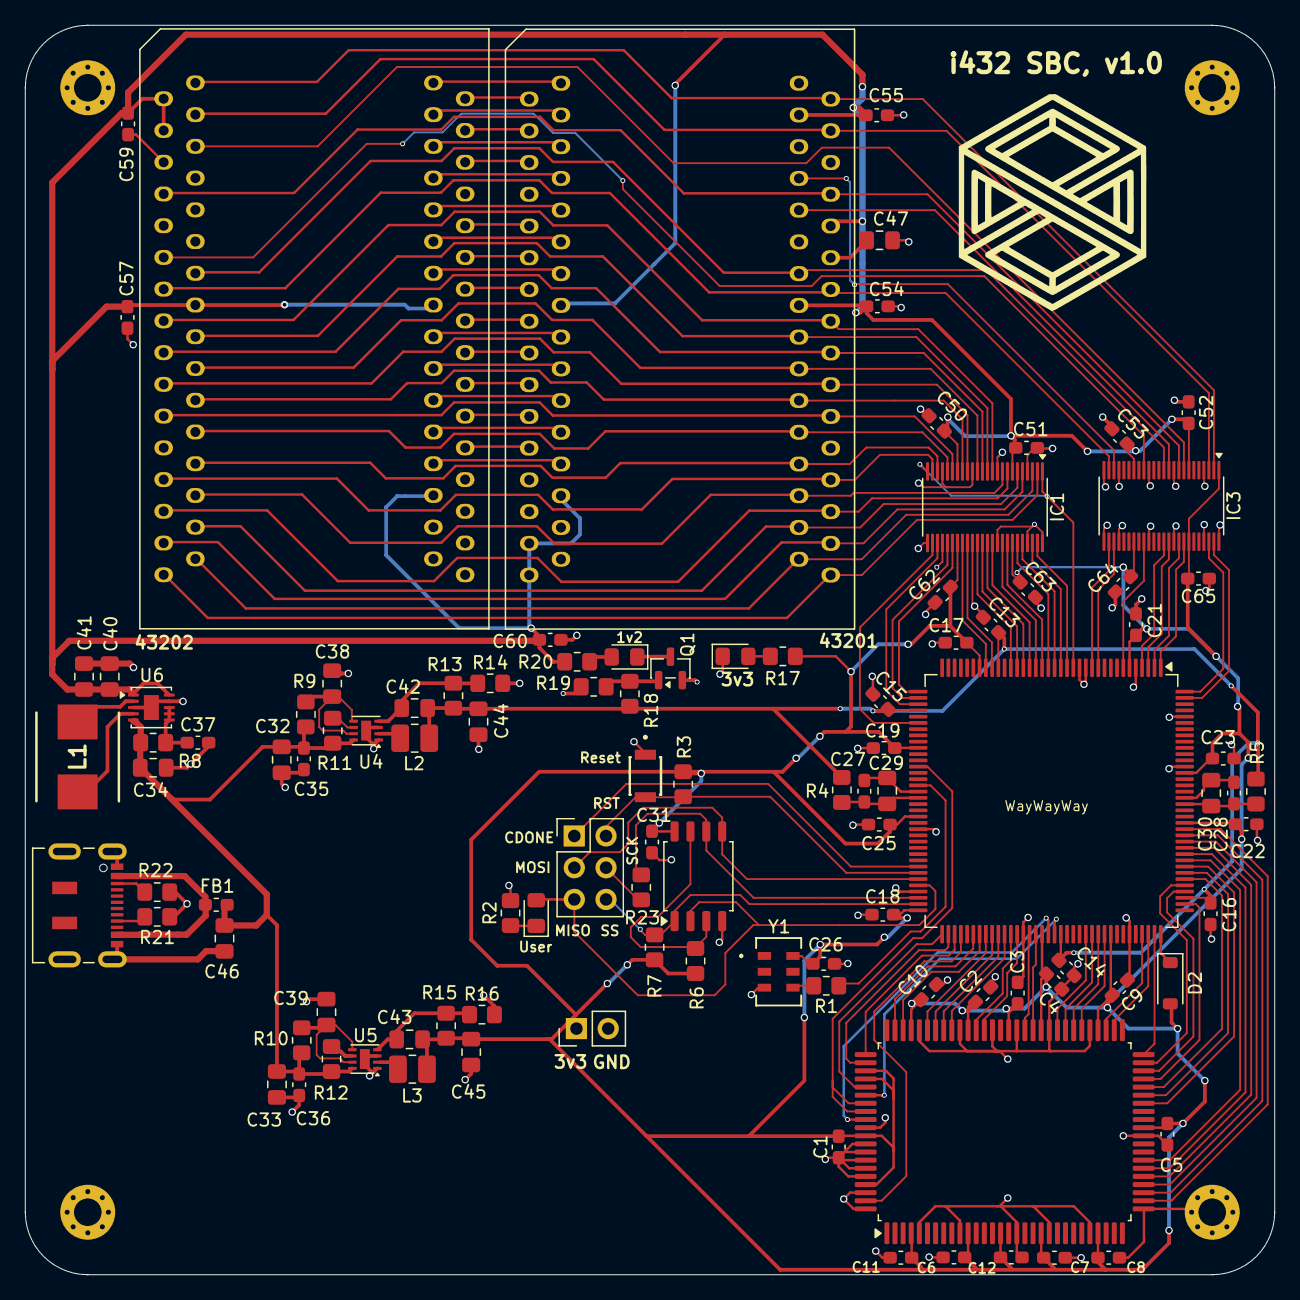
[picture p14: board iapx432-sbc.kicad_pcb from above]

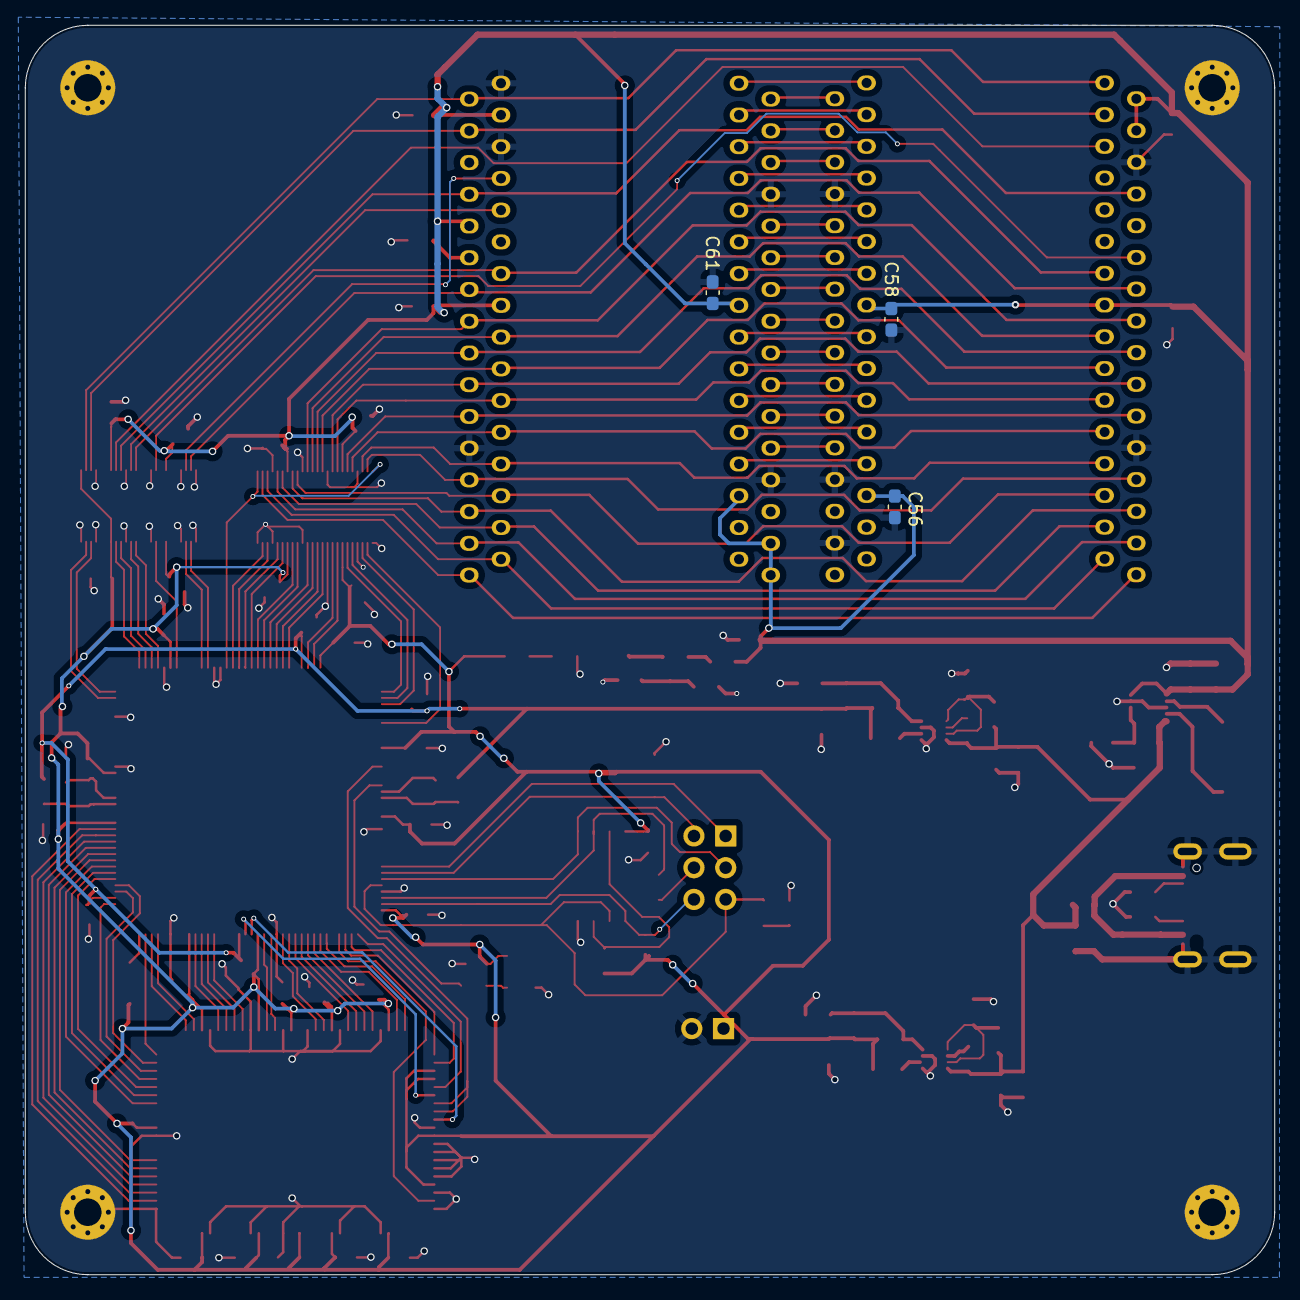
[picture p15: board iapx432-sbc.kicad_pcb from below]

Board: 2 copper layers, 100.0 x 100.0 mm, 112 parts (3 on the bottom side), 150 nets.

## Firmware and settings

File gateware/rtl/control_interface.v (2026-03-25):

module control_interface #(
  parameter WRITE_LOG_ADDR_WIDTH = 6,
  parameter BUS_LOG_ADDR_WIDTH = 10
)(
  input wire clk,   // 50Mhz
  input wire rst_n,

  // UART interface
  input            uart_rx_io,
  output reg [7:0] uart_tx_data,
  output reg       uart_tx_req,
  input            uart_tx_busy,

  // SRAM interface (16-bit wide external SRAM; UART still moves 8-bit payloads)
  output reg         sram_req,
  output reg         sram_wr,
  output reg         sram_rd,
  output reg  [15:0] sram_addr,
  output reg  [15:0] sram_wdata,
  input  wire [15:0] sram_rdata,
  input  wire        sram_busy,
  input  wire        sram_data_valid,

  // UART log access to BRAM
  output reg [BUS_LOG_ADDR_WIDTH-1:0] u_log_addr,
  output reg [23:0] u_log_data_in,
  input      [23:0] u_log_data_out,
  input             u_log_data_valid,
  output reg        u_log_wr,
  output reg        u_log_rd,

  // UART log access to write log
  output reg [WRITE_LOG_ADDR_WIDTH-1:0] u_wlog_addr,
  input      [31:0] u_wlog_data_out,
  output reg        u_wlog_rd,

  // signals to GDP interface
  output reg gdp_trigger_init
);
  wire [7:0] uart_rx_data;
  wire uart_rx_valid;
  wire uart_rx_busy;
  uart_rx uart_receiver (
    .clk(clk),
    .rst_n(rst_n),
    .rx_io(uart_rx_io),
    .data_out(uart_rx_data),
    .data_valid(uart_rx_valid),
    .busy(uart_rx_busy)
  );

  // output command opcodes
  localparam CMD_OUT_ACK = 8'h01, CMD_OUT_ERR = 8'hFF;

  // input command opcodes (high bit means that there is no parameters for function)
  localparam CMD_IN_SRAM_BULK_WRITE = 8'h01,
             CMD_IN_SRAM_WRITE = 8'h02,
             CMD_IN_SRAM_READ = 8'h03,
             CMD_IN_LOG_WR = 8'h10,
             CMD_IN_LOG_RD = 8'h11,
             CMD_IN_GDP_START = 8'h81,
             CMD_IN_PING = 8'h80,
             CMD_IN_WLOG_RD = 8'h90;

  // common command FSM
  localparam CMD_STATE_IDLE = 3'd0,
             CMD_STATE_READ_DATA = 3'd1,
             CMD_STATE_READY = 3'd2,
             CMD_STATE_FINISHED = 3'd3,
             CMD_STATE_ACKED = 3'd4,
             CMD_STATE_ERROR = 3'd5;

  // FSM for READ_DATA command
  localparam SRAM_RD_REQ = 4'd0,
             SRAM_RD_READ = 4'd1,
             SRAM_RD_DATA_HI = 4'd2,
             SRAM_RD_DATA_HI_GAP = 4'd3,
             SRAM_RD_DATA_LO = 4'd4,
             SRAM_RD_DATA_LO_GAP = 4'd5;

  // FSM for WRITE_DUMP command
  localparam SRAM_BLKWR_READ_WORD = 4'd0, SRAM_BLKWR_WRITE_WORD = 4'd1, SRAM_BLKWR_NEXT_WORD = 4'd2;

  // FSM for LOG_RD
  localparam LOG_RD_REQ         = 4'd0,
             LOG_RD_TYPE        = 4'd1,
             LOG_RD_TYPE_GAP    = 4'd2,
             LOG_RD_ADDR_HI     = 4'd3,
             LOG_RD_ADDR_HI_GAP = 4'd4,
             LOG_RD_ADDR_LO     = 4'd5,
             LOG_RD_ADDR_LO_GAP = 4'd6;

  // FSM for WLOG_RD
  localparam WLOG_RD_REQ = 4'd0,
             WLOG_RD_SEND_DATA0 = 4'd1,
             WLOG_RD_SEND_DATA0_GAP = 4'd2,
             WLOG_RD_SEND_DATA1 = 4'd3,
             WLOG_RD_SEND_DATA1_GAP = 4'd4,
             WLOG_RD_SEND_DATA2 = 4'd5,
             WLOG_RD_SEND_DATA2_GAP = 4'd6,
             WLOG_RD_SEND_DATA3 = 4'd7,
             WLOG_RD_CHECK_DONE = 4'd8;

  reg [ 2:0] in_state;
  reg [ 3:0] in_cmd_state;
  reg [ 7:0] in_cmd_opcode;
  reg [15:0] in_cmd_addr;
  reg [23:0] in_cmd_value;
  reg [ 2:0] in_byte_count;
  reg [23:0] log_rd_data;
  reg        log_rd_valid;
  reg [15:0] sram_rd_data;
  reg [31:0] wlog_rd_data;
  reg        bulk_write_wait_low_byte;

  localparam [7:0] LOG_TYPE_WRITE = 8'h01;
  localparam [7:0] LOG_TYPE_READ = 8'h02;

  always @(posedge clk) begin
    if (!rst_n) begin
      in_state <= CMD_STATE_IDLE;
      in_byte_count <= 3'd0;
      in_cmd_state <= 0;
      in_cmd_opcode <= 0;
      in_cmd_addr <= 0;
      in_cmd_value <= 0;
      log_rd_data <= 0;
      log_rd_valid <= 1'b0;
      sram_rd <= 0;
      sram_wr <= 0;
      u_log_wr <= 0;
      u_log_rd <= 0;
      bulk_write_wait_low_byte <= 1'b0;
      u_wlog_rd <= 1'b1;
      u_wlog_addr <= {WRITE_LOG_ADDR_WIDTH{1'b0}};
    end
    else begin
      // pulses
      gdp_trigger_init <= 0;
      u_log_wr <= 0;
      u_log_rd <= 0;
      sram_wr <= 0;
      sram_rd <= 0;

      if (u_log_data_valid) begin
        log_rd_data  <= u_log_data_out;
        log_rd_valid <= 1'b1;
      end
      case (in_state)
        CMD_STATE_IDLE: begin
          sram_req <= 0;
          in_byte_count <= 3'd0;
          // assume that first state for each command is idle state
          in_cmd_state <= 0;

          if (uart_rx_valid) begin
            sram_req <= 1;
            in_cmd_opcode <= uart_rx_data;
            // commands without parameters
            if (uart_rx_data[7] == 1'b1) in_state <= CMD_STATE_READY;
            else in_state <= CMD_STATE_READ_DATA;
          end
        end

        CMD_STATE_READ_DATA: begin
          // BULK_WRITE 0x01 wordCountHi wordCountLo dataHi[N] dataLo[N] dataHi[N-1] dataLo[N-1] .... dataHi[0] dataLo[0]
          if (in_cmd_opcode == CMD_IN_SRAM_BULK_WRITE && in_byte_count == 3'd2) begin
            case (in_cmd_state)
              SRAM_BLKWR_READ_WORD: begin
                if (uart_rx_valid) begin
                  if (!bulk_write_wait_low_byte) begin
                    in_cmd_value[15:8]       <= uart_rx_data;
                    bulk_write_wait_low_byte <= 1'b1;
                  end
                  else begin
                    in_cmd_value[7:0]        <= uart_rx_data;
                    in_cmd_addr              <= in_cmd_addr - 1;
                    in_cmd_state             <= SRAM_BLKWR_WRITE_WORD;
                    bulk_write_wait_low_byte <= 1'b0;
                  end
                end
              end

              SRAM_BLKWR_WRITE_WORD: begin
                sram_wdata <= in_cmd_value[15:0];
                sram_wr <= 1;
                sram_addr <= in_cmd_addr;
                if (!sram_busy) begin
                  in_cmd_state <= SRAM_BLKWR_NEXT_WORD;
                end
              end

              SRAM_BLKWR_NEXT_WORD: begin
                if (in_cmd_addr == 0) in_state <= CMD_STATE_FINISHED;
                else in_cmd_state <= SRAM_BLKWR_READ_WORD;
              end
            endcase
          end
          else if (uart_rx_valid) begin
            case (in_byte_count)
              3'd0: in_cmd_addr[15:8] <= uart_rx_data;
              3'd1: begin
                in_cmd_addr[7:0] <= uart_rx_data;
                if (in_cmd_opcode == CMD_IN_SRAM_READ || in_cmd_opcode == CMD_IN_LOG_RD)
                  in_state <= CMD_STATE_READY;
              end
              3'd2: in_cmd_value[15:8] <= uart_rx_data;
              3'd3: begin
                in_cmd_value[7:0] <= uart_rx_data;
                if (in_cmd_opcode == CMD_IN_SRAM_WRITE) in_state <= CMD_STATE_READY;
              end
              3'd4: begin
                in_cmd_value[23:16] <= uart_rx_data;
                in_state <= CMD_STATE_READY;
              end
            endcase
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

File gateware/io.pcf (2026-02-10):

# Control
set_io SRAM_STROBE 73
set_io SRAM_CLK    90
set_io SRAM_OE     91
set_io SRAM_WR     49

# Address bus
set_io SRAM_A[0] 117
set_io SRAM_A[1] 118
set_io SRAM_A[2] 122
set_io SRAM_A[3] 121
set_io SRAM_A[4] 120
set_io SRAM_A[5] 119
set_io SRAM_A[6] 116
set_io SRAM_A[7] 115
set_io SRAM_A[8] 114
set_io SRAM_A[9] 110
set_io SRAM_A[10] 112
set_io SRAM_A[11] 113
set_io SRAM_A[12] 107
set_io SRAM_A[13] 75
set_io SRAM_A[14] 74
set_io SRAM_A[15] 76

# Data bus
set_io SRAM_D[0]  106
set_io SRAM_D[1]  105
set_io SRAM_D[2]  99
set_io SRAM_D[3]  98
set_io SRAM_D[4]  97
set_io SRAM_D[5]  96
set_io SRAM_D[6]  88
set_io SRAM_D[7]  87
set_io SRAM_D[8]  85
set_io SRAM_D[9]  84
set_io SRAM_D[10] 83
set_io SRAM_D[11] 82
set_io SRAM_D[12] 81
set_io SRAM_D[13] 80
set_io SRAM_D[14] 79
set_io SRAM_D[15] 78

# Clock / reset / control
set_io PCLK  1
set_io CLR   2
set_io INIT  3
set_io ICS   4
set_io BOUT  7
set_io FATAL 11
set_io PRQ   12

# Address / control/data (ACD bus)
set_io ACD_DIRECTION 15
set_io ACD[0]  16
set_io ACD[1]  17
set_io ACD[2]  18
set_io ACD[3]  19
set_io ACD[4]  20
set_io ACD[5]  21
set_io ACD[6]  42
set_io ACD[7]  39
set_io ACD[8]  38
set_io ACD[9]  37
set_io ACD[10] 29
set_io ACD[11] 28
set_io ACD[12] 25
set_io ACD[13] 24
set_io ACD[14] 23
set_io ACD[15] 22

set_io CLKA 143
set_io CLKB 144
set_io CLK_250 52

set_io UART_RX 70
set_io UART_TX 67
set_io LED 68

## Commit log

2026-02-10 bom fmt
2026-02-10 more compact BOM
2026-02-11 adopt UART interface to 16-bit words
2026-02-17 build delay port and delay carrier objects + support 1-byte writes + fix local comm segment + QoL changes
    [control_interface.v]
